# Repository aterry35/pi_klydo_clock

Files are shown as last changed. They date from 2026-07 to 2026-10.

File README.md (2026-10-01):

# Pi Klydo Clock

An offline-first animated art clock for a Raspberry Pi 3 and a portrait 7-inch
DSI display. The repository contains both the native clock renderer and a browser
designer that exports installable clock-face packages.

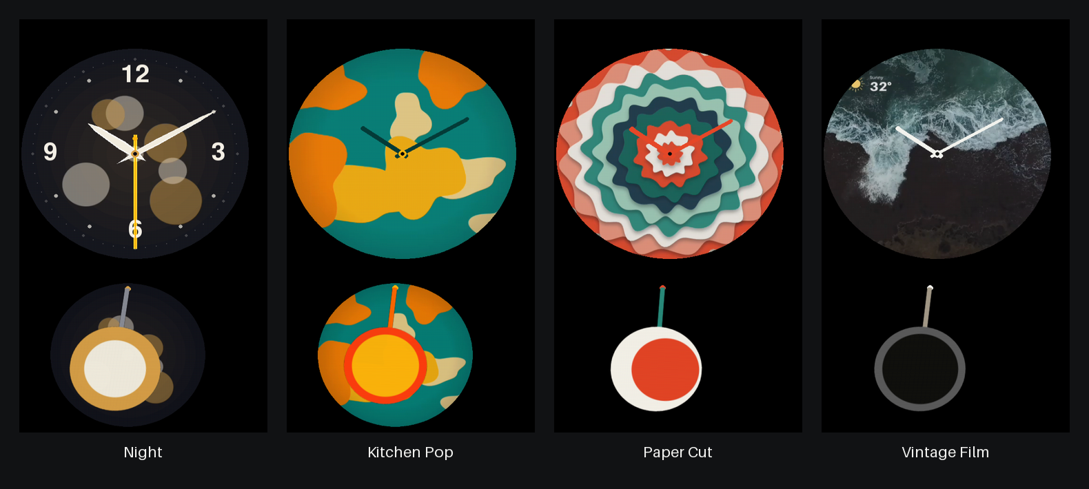
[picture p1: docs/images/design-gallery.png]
Kitchen Pop, Night, Paper Cut, and Vintage Film clock designs


## Highlights

- Native SDL2/Pygame renderer with PyAV video loops; Chromium is not required on the Pi.
- Real-time analog hands rendered independently from the background animation.
- Animated pendulum art with configurable period, amplitude, pivot, and backdrop.
- JSON-configurable display geometry shared by the renderer and design tool.
- Built-in designs plus SD-card and SCP design-folder discovery after every boot.
- DS3231 RTC support, NTP synchronization, and SoftAP Wi-Fi provisioning.
- Four-second dial hold opens an on-device network recovery panel.
- Optional MQTT face selection by folder ID, with retained state and face catalogue.
- React/Vite designer with deterministic H.264 export and package validation.
- Public community gallery with artist profiles, watermarks, likes, comments, reports, and ZIP downloads.
- Private moderation dashboard with hide/restore, artist suspension, and an audit history.

The target enclosure uses a **480 x 800** display behind two circular cutouts:

- **Top circle** — a **400 px** looping design video/animation with **real-time analog hands
  composited on top as an independent layer** (the hands are driven by the clock, not
  the video, so they stay correct no matter what the animation does). The background
  fills the complete opening; the 3D-printed faceplate supplies the visible edge.
- **Bottom circle** — a **300 px themed swinging pendulum**, colour/period/amplitude matched
  to the active design.

Designs live on the SD card, one folder each. Timekeeping supports a **DS3231 RTC** (correct
with no network); Wi-Fi is provisioned via a **SoftAP captive portal** without touching
the display.

See [`DESIGN_REVIEW.md`](DESIGN_REVIEW.md) for why this replaced the original Chromium/HTML
artifact (kept in [`legacy/`](legacy/)). See [`UI_CONFIGURATION.md`](UI_CONFIGURATION.md)
for the design-folder contract, daily/manual selection logic, and future GPIO/remote
control extension points.

---

## Repo layout

```
DESIGN_REVIEW.md        findings on the old HTML + the architecture decision
UI_CONFIGURATION.md     design-folder schema, controls, AI design contract
COMMUNITY_DESIGNS.md    SD-card/SCP copy workflow + artist package contract
config/clock.json       shared device geometry, folders, and design limits
docs/images/            renderer-generated design screenshots for documentation
3d_enclosure/*.stl      printable frame, faceplate, and rear enclosure meshes
deploy/                 public designer Caddy configuration and deployment notes
community/              Flask API, SQLite schema, design storage, seeding, and backups
Tools/clock-design-creator-app/app/
                        Browser editor for building validated design ZIPs
CLAUDE_DESIGN_APP_PROMPT.md prompt for building a design creator app
legacy/Pi Clock.html    the original bundled-React artifact (kept, untouched)
designs/<name>/         one folder per design (fully self-describing)
  loop.mp4|webm         background animation for the top circle (480×480)
  pendulum.png|svg      pendulum sprite (pivot at top-centre)
  theme.json            hands, dial, pendulum physics, ambiance
src/piclock/            the renderer (see cli.py for entry point)
scripts/                install, validation, generators, and preview rendering
provisioning/           comitup.conf (SoftAP captive portal)
systemd/                renderer, network helper, and RTC-sync units
boot/                   config.txt snippet + cmdline.txt notes
```

On the Pi, community/user designs are also scanned at startup from:

```text
/boot/firmware/piclock-designs/
/boot/piclock-designs/
~/piclock-designs/
```

---

## 3D-printable enclosure

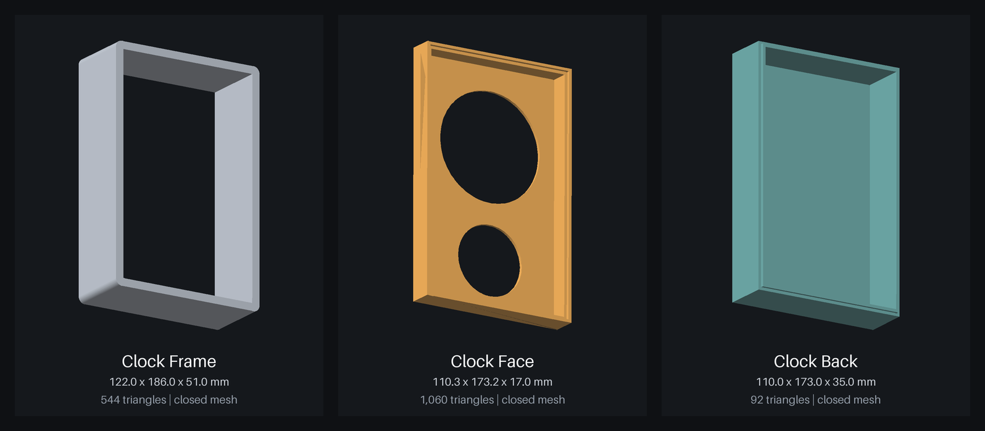
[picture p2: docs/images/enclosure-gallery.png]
Clock frame, faceplate, and rear enclosure STL previews


The [`3d_enclosure/`](3d_enclosure/) directory contains the three closed, manifold
binary STL meshes used for the clock enclosure. Import them into the slicer at 100%
scale and interpret the unitless STL coordinates as millimetres.

| File | Part | Mesh bounding box |
| --- | --- | --- |
| [`clock_frame.stl`](3d_enclosure/clock_frame.stl) | Outer frame and surround | 122.0 x 186.0 x 51.0 mm |
| [`clock_face.stl`](3d_enclosure/clock_face.stl) | Front insert with dial and pendulum openings | 110.34 x 173.216 x 17.0 mm |
| [`clock_back.stl`](3d_enclosure/clock_back.stl) | Rear enclosure shell | 110.0 x 173.0 x 35.0 mm |

The dimensions above are axis-aligned mesh bounds, not recommended print
orientation. Confirm display fit, connector clearance, shrinkage, and printer
tolerances before a production print. Regenerate the documentation renders after
changing an STL with:

```bash
./.venv/bin/python scripts/render_stl_previews.py
```

---

## Quick start (development, on a Mac/PC)

```bash
python3 -m venv .venv && ./.venv/bin/pip install -r requirements.txt
./.venv/bin/python scripts/make_sample_design.py         # writes examples/testcard/
cd src && ../.venv/bin/python -m piclock.cli --windowed --designs ../examples \
  --state ../.piclock-state.json
```

A 480×800 window opens with the sample design. **Controls:** click/tap the top circle (or
`←`/`→`) to cycle designs and persist a manual choice; `d` returns to daily rotation;
`space` toggles night dimming; `esc`/`q` quits.

## Run the design creator

The public community site is available at
<https://designer.18-191-209-51.sslip.io>. It is a community-led, open-source,
non-commercial project: the service does not currently charge artists, sell
submitted designs, or run advertising. Project contact:
<agnel.terry@gmail.com>.

Public routes:

- `/` — project invitation, featured designs, and artist/maker entry points
- `/artists` — browser designer, attribution, licensing, and review guide
- `/designer` — the production clock-face creator
- `/community` — approved designs, likes, comments, reports, and downloads
- `/build` — Raspberry Pi, display, enclosure, installation, and recovery guide
- `/admin` — private review and moderation dashboard

Local editing and ZIP export do not require an account. Submitting to the
Community page requires an artist account.
New packages remain private until an administrator reviews and approves them;
approved packages, previews, likes, and comments are stored by the community API.

```bash
cd Tools/clock-design-creator-app/app
npm install
npm run dev
```

Open the URL printed by Vite in current Chrome or Edge. The editor keeps imported
media local, previews the production enclosure geometry, and exports a ZIP containing
`loop.mp4`, `pendulum.png`, `theme.json`, a preview, and a validation report.

```bash
npm test
npm run build
```

See [`Tools/clock-design-creator-app/README.md`](Tools/clock-design-creator-app/README.md)
for the complete editor and export contract. See
[`COMMUNITY_SOFT_OPENING.md`](COMMUNITY_SOFT_OPENING.md) for the hosted service,
operating procedure, backups, and soft-opening limitations.

---

## Designs & `theme.json`

A design folder **fully defines** the design — there are no hardcoded assets. Anything
missing degrades gracefully (a flat accent disc / procedural pendulum), so a folder with
only a partial `theme.json` still renders.

```jsonc
{
  "name": "Test Card",
  "creator": {
    "artist": "Artist Name",
    "watermark": "Artist Name",
    "watermark_enabled": true,
    "watermark_color": "#ffffff",
    "watermark_opacity": 0.65
  },
  "accent": "#d9a24a",          // hub, pendulum ring, dial accents
  "background": "#050505",       // used when day_night is off
  "hands": {
    "hour":   { "color": "#f0c070", "width": 12, "length": 0.52,
                "glow": true, "shape": "spindle" },
    "minute": { "color": "#f7e1d3", "width": 7,  "length": 0.78,
                "glow": true, "shape": "spindle" },
    "second": { "color": "#e0564a", "width": 3,  "length": 0.90,
                "glow": true, "visible": true }
  },
  "dial":     { "markings": "ticks", "color": "#ffffff", "count": 12 },
  "pendulum": { "period_s": 2.0, "amplitude_deg": 13,
                "pivot": [0.5, 0.05], "rod_length": 0.82 },
  "bottom":   { "backdrop": "loop", "color": "#050505" },
  "ambiance": { "day_night": true, "twinkle": true, "glow": true }
}
```

- `length` / `rod_length` are fractions of the circle radius/diameter.
- Set a hand's `visible` to `false` for clean Klydo-style designs with no
  second hand.
- `shape` can be `spindle` for pointed clock hands or `rounded` for clean
  baton hands like the Klydo reference photos.
- `pivot` is `[x, y]` as a fraction of the bottom circle's bounding box.
- `period_s` = one full left→right→left swing; `amplitude_deg` = peak angle.
- `bottom.backdrop` can be `loop`, `solid`, or `none`; use `solid` plus a
  `color` for reference designs where the pendulum sits on a plain cutout.

### Add a new design
1. Create `designs/my-design/`.
2. Drop in a **480×480** `loop.mp4` (H.264, short seamless loop) and a `pendulum.png`
   or `pendulum.svg` (transparent artwork, pivot at top-centre).
3. Write a `theme.json` (copy `examples/testcard/theme.json` and edit).
4. Cycle to it on the device (tap/swipe the top circle). No code changes, no restart
   config — the folder is discovered at startup.

For community designs, copy the complete folder to
`/boot/firmware/piclock-designs/` by mounting the SD card on a laptop, or SCP it
to `~/piclock-designs/` on the Pi. Power-cycle or restart the renderer to scan
new folders. See `COMMUNITY_DESIGNS.md` for the full package contract.

To create a package in the browser, run the production editor in
`Tools/clock-design-creator-app/app/`. Its README includes installation,
browser support, testing, and export instructions.

By default the renderer starts in **daily** mode: it chooses a deterministic design for
the current date. Tap/swipe/arrow keys switch to a manual design and save that choice in
the state file. Press `d` to return to daily rotation.

Hold the upper dial without moving for four seconds to open **Network Recovery**.
The normal tap action is suppressed after a successful long press. The panel shows
connection state, current IP address, nearby SSIDs, refresh, and close controls.

`scripts/make_sample_design.py` shows how to generate a loop + pendulum + theme
programmatically (it uses PyAV to encode, so no system ffmpeg is required).

## Clock-wide JSON configuration

See [`docs/MQTT_CONTROL.md`](docs/MQTT_CONTROL.md) for MQTT configuration, topics,
and remote face selection. MQTT is disabled by default; device configuration
enables it without changing any design folders.

Device registration was previously split between code and systemd command-line
arguments. It now comes from [`config/clock.json`](config/clock.json), which is
also consumed by the browser designer.

The renderer merges the bundled file with persistent device and SD-card overrides:

```text
/opt/piclock/config/clock.json
/etc/piclock/clock.json
/boot/piclock-config.json
/boot/firmware/piclock-config.json
```

Later files win and may contain only changed fields. To tune the remaining left/right
registration without changing any design package:

```json
{
  "layout": {
    "dial": { "center": [224, 260] },
    "pendulum": { "center": [210, 650] }
  }
}
```

The installer preserves `/etc/piclock/clock.json` on later upgrades. See
[`config/README.md`](config/README.md) for precedence and the complete field guide.
Per-design art remains in `theme.json`; physical positions must not be copied into
every design.

---

## DS3231 RTC wiring (Raspberry Pi 3, I2C1)

| DS3231 pin | Pi header pin | Signal |
|---|---|---|
| VCC | Pin 1 | 3.3 V  |
| GND | Pin 6 | GND |
| SDA | Pin 3 | GPIO2 / SDA1 |
| SCL | Pin 5 | GPIO3 / SCL1 |

The [`config.txt` snippet](boot/config.txt.snippet) enables I2C and loads
`dtoverlay=i2c-rtc,ds3231`. After install + reboot, verify:

```bash
i2cdetect -y 1     # a device at 0x68 (shows "UU" once the kernel driver claims it)
sudo hwclock -r    # reads the DS3231
```

`install.sh` removes `fake-hwclock` so the DS3231 becomes the real time source — the
clock is correct on power-up **with no network**. When Wi-Fi is available and NTP syncs,
`piclock-rtc-sync` writes the corrected time **back** to the DS3231 (hourly + shortly
after boot). With no network it is a no-op, so the RTC is never overwritten with drift.

---

## Portrait rotation (display and touch are SEPARATE)

**Display** — preferred: rotate at the framebuffer via the kernel cmdline (zero per-frame
cost), e.g. `video=DSI-1:800x480@60,rotate=90`. See
[`boot/cmdline.txt.notes`](boot/cmdline.txt.notes) for how to find your DSI connector
name. In-app fallback: `--rotate 90`.

Some 800x480 DSI panels use rectangular physical pixels, which makes a pixel-perfect
circle appear taller than it is wide after portrait rotation. Set
`display.circle_y_scale` to correct each complete dial and pendulum layer without
moving its centre. Measure the displayed width and height and use `width / height` as
the factor. This project's measured panel uses `0.925`.

The default circle centres are registered to the printed 102 x 165 mm front panel:
the 76 mm dial opening starts at `(14.9954, 16.4983)` mm and the 48.5 mm pendulum
opening starts at `(29.0742, 107.4681)` mm. Background layers overscan those
openings; the enclosure supplies the visible black border.

Enclosure registration is global rather than part of a design package. Set
`layout.dial.center` and `layout.pendulum.center` in the device JSON to move all
designs together. The current enclosure calibration uses `(224,260)` for the dial
and `(210,650)` for the pendulum.
The CLI offset options remain available only for temporary on-device experiments.

**Touch** — rotating the display does **not** rotate the touch matrix. Two options:
- In-app: `--touch-rotate 90` (the renderer rotates normalised finger coords).
- System: a libinput calibration matrix via udev, e.g.
  ```
  # /etc/udev/rules.d/99-piclock-touch.rules  (90° example)
  ENV{LIBINPUT_CALIBRATION_MATRIX}="0 -1 1 1 0 0"
  ```
Tune the exact value on-device; touch calibration is inherently panel-specific.

---

## Wi-Fi provisioning (SoftAP captive portal, via comitup)

The clock UI runs regardless of network state. If no known network connects on boot,
[comitup](provisioning/comitup.conf) raises an open access point **`PiClock-XXXX`**:

1. On your phone, join `PiClock-XXXX` → a captive portal opens.
2. Pick your Wi-Fi network and enter the password.
3. The Pi drops the AP, joins your network, and NTP→RTC writeback runs.

The clock keeps rendering through the whole flow. For recovery from a stale or incorrect
saved network, hold the upper dial for four seconds and choose **Start Setup Hotspot**.
The panel requires a second confirmation because this operation removes all saved Wi-Fi
profiles, disconnects any SSH session, and returns Comitup to hotspot mode. Join the shown
`PiClock-XXXX` network on a phone and use its captive portal to enter the replacement Wi-Fi
credentials. After connection, the recovery panel shows the DHCP address directly; Comitup
also advertises its `PiClock-XXXX.local` mDNS name through Avahi.

The renderer remains unprivileged. Network status, scanning, and the confirmed Comitup
reset pass over `/run/piclock-network/control.sock` to the root-owned
`piclock-network.service`, whose protocol allowlists only those three operations.

Useful diagnostics after installation:

```bash
systemctl status NetworkManager comitup comitup-web piclock-network
journalctl -u comitup -u comitup-web -u piclock-network -b
nmcli device status
```

---

## Boot-time tuning (applied)

Targeting fast power-on → first frame on a DSI panel (no HDMI):

- **No HDMI probing** — `dtoverlay=vc4-kms-v3d,nohdmi` disables HDMI outputs (DSI panel).
- **No splash / quiet boot** — `disable_splash=1`, and cmdline `quiet loglevel=1
  logo.nologo plymouth.enable=0 vt.global_cursor_default=0 fastboot`.
- **Renderer starts before Wi-Fi** — `piclock-renderer.service` orders after `local-fs`
  only and never references `network-online.target`, so the first frame is not gated on
  Wi-Fi. `getty@tty1` is disabled so the app owns the console.
- **`boot_delay=0`**, `Restart=always` watchdog on the renderer.

### Read-only root (SD longevity — optional, recommended)
An always-on appliance benefits from a read-only root to avoid SD wear/corruption. Enable
via `raspi-config` → *Performance* → *Overlay File System*, or `raspi-config nonint
enable_overlayfs`. Keep these paths writable:
- the DS3231 needs none (it is hardware), but `hwclock` drift files under `/var` do;
- comitup stores connection profiles under `/etc/NetworkManager/system-connections`.
Put those on a small writable overlay/tmpfs exception, or provision Wi-Fi once before
switching root to read-only. Designs on the SD card are read-only by nature.

---

## Install on the Pi

```bash
git clone https://github.com/aterry35/pi_klydo_clock.git piclock
cd piclock
sudo bash scripts/install.sh
```

The installer defaults the wireless regulatory country to `US`. Override it when needed:

```bash
sudo PICLOCK_WIFI_COUNTRY=CA bash scripts/install.sh
```

The installer (idempotent) installs deps, deploys to `/opt/piclock`, builds the venv
(via piwheels), enables I2C + the DS3231, configures the Wi-Fi country, appends the
`config.txt` block, installs NetworkManager/Comitup/captive-portal support and the
systemd units, and disables `getty@tty1`. On Bookworm it first installs Comitup's
official APT source package to obtain the required NetworkManager Python bindings;
installation now stops if SoftAP support cannot be installed.
It then prints the **manual** cmdline.txt step (not automated — a bad cmdline can prevent
boot) and the DS3231 verification commands.

By default, the renderer service runs as the sudo/login user that ran the installer
(for this Pi, that means the display-owning desktop user). Override with
`PICLOCK_USER=piclock sudo bash scripts/install.sh` if you want a dedicated service user,
then validate DRM/input permissions on the physical Pi.

```bash
systemctl status piclock-renderer
journalctl -u piclock-renderer -b
```

> **DRM master note:** running an SDL kmsdrm app straight from systemd (no compositor)
> requires the process to become DRM master on tty1. The provided unit takes the VT and
> runs in the `video`/`render`/`input` groups; if the display stays black, check
> `journalctl -u piclock-renderer -b` for a DRM permission error and confirm `getty@tty1`
> is disabled. This is the one piece that can only be validated on the physical Pi.

---

## What is verified vs. Pi-only

Verified on a development machine: design-folder discovery + `theme.json`, PyAV loop decode,
the two-layer composite, **hands decoupled from the video**, pendulum swing, circle-only
day/night ambiance + twinkle, graceful fallback for asset-less designs, design cycling,
and persisted daily/manual selection.

Verified on the project Pi: KMS portrait rendering, JSON geometry overrides, systemd
startup, design discovery, persistent selection, and native H.264 playback. DS3231 wiring
and the complete captive-portal/long-press recovery flow still require validation after
the freshly imaged Pi is available.

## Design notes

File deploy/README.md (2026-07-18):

# Designer deployment

The production designer is served by Caddy at:

<https://designer.18-191-209-51.sslip.io>

The root serves the public landing page. Clean SPA paths include `/artists`,
`/designer`, `/community`, `/build`, and `/admin`; Caddy's `try_files` fallback
routes direct requests for each page to the Vite application.

The hostname uses `sslip.io` DNS to resolve to the EC2 public IP. Caddy obtains and
renews the TLS certificate automatically. Ports 80 and 443 must be allowed by the
instance's EC2 security group.

## Deploy an update

From the repository root:

```bash
DESIGNER_KEY=Amazon_certificate/Terryt.pem ./scripts/deploy_designer_ec2.sh
```

The script runs the designer and API tests, builds the Vite application, uploads
timestamped frontend and backend releases, seeds the bundled designs into the
community gallery, validates Caddy, and atomically changes each `current` symlink.
Previous frontend releases remain under `/var/www/pi-clock-designer/releases/` and
backend releases under `/opt/pi-clock-community/releases/` for rollback.

## Services and data

```text
piclock-community.service          Gunicorn/Flask API on 127.0.0.1:8080
piclock-community-backup.timer     daily SQLite backup with 14-day retention
/var/lib/pi-clock-community/       database, uploaded ZIPs/previews, and backups
/opt/pi-clock-community/current/   active API release
/var/www/pi-clock-designer/current active frontend release
/etc/piclock-community.env       private agent token hash and agent identity
```

Caddy serves the frontend and proxies `/api/*` to Gunicorn. Check the deployed
service with:

```bash
curl https://designer.18-191-209-51.sslip.io/api/health
ssh -i Amazon_certificate/Terryt.pem ubuntu@18.191.209.51 \
  'sudo systemctl status piclock-community --no-pager'
```

The EC2 instance is the only application host during the soft opening. Backups are
local to that instance, so copy them off-host before treating the service as durable.
See `COMMUNITY_SOFT_OPENING.md` for current limits and operating steps.

Promote an existing account without handling its password:

```bash
cd /opt/pi-clock-community/current
sudo -u piclock-community env PICLOCK_DATA_DIR=/var/lib/pi-clock-community \
  /opt/pi-clock-community/venv/bin/python -m community.manage promote \
  --email administrator@example.com
```

The private key is excluded by `*.pem` in the repository `.gitignore` and must never be
copied into the web root or committed to Git.

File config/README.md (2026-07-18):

# Clock Configuration

`clock.json` is the shared source of truth for device-wide rendering and design
package limits. Both the native clock renderer and the browser designer read it.

The calibrated Pi layout and the browser preview use separate center settings.
This keeps artwork centered in the designer without changing its alignment with
the physical enclosure on the clock.

## Configuration Levels

The clock deliberately uses two JSON levels:

- `clock.json` controls the physical device: display, circle positions, size
  limits, enclosure measurements, design folders, and asset requirements.
- Each design folder's `theme.json` controls its artwork: hands, dial markings,
  circle diameter within the allowed range, pendulum motion, and colors.

Physical registration does not belong in every design. Changing a center in
`clock.json` moves every installed design together.

## Load Order

The renderer merges these files in order. Later values override earlier values:

1. `/opt/piclock/config/clock.json` (installed project defaults)
2. `/etc/piclock/clock.json` (persistent device calibration)
3. `/boot/piclock-config.json` (older Raspberry Pi OS boot partition)
4. `/boot/firmware/piclock-config.json` (Bookworm boot partition)
5. Any file passed with `--config`

The installer initializes `/etc/piclock/clock.json` from
`device-clock.example.json` only when the device file does not already exist.
Subsequent installs preserve the device calibration.

Override files may contain only the fields that need changing. For example:

```json
{
  "layout": {
    "dial": { "center": [224, 260] },
    "pendulum": { "center": [210, 650] }
  }
}
```

After changing a file on the Pi, restart the renderer:

```bash
sudo systemctl restart piclock-renderer
```

Invalid override files are reported in the service journal and ignored so that
a malformed SD-card configuration cannot stop the clock from booting.

## Main Fields

| JSON path | Purpose |
|---|---|
| `display.mode` | `kms` on the Pi or `windowed` for desktop use. |
| `display.width`, `display.height` | Portrait render canvas. |
| `display.rotate`, `display.touch_rotate` | Display and touch orientation. |
| `display.circle_y_scale` | Physical pixel aspect correction. |
| `layout.dial.center` | Upper circle center `[x, y]` in canvas pixels. |
| `layout.pendulum.center` | Lower circle center `[x, y]` in canvas pixels. |
| `designer.preview.dial_center` | Upper circle center used only by the browser designer and exported preview image. |
| `designer.preview.pendulum_center` | Lower circle center used only by the browser designer and exported preview image. |
| `network.enabled` | Enables the on-device long-press network recovery panel. |
| `network.interface` | NetworkManager Wi-Fi device controlled by the helper. |
| `network.control_socket` | Renderer/helper Unix socket under `/run/piclock-network`. |
| `network.long_press_seconds` | Stationary upper-dial hold duration required to open recovery. |
| `network.max_visible_networks` | Number of nearby SSIDs shown inside the dial. |
| `layout.*.minimum_diameter` | Smallest diameter accepted from `theme.json`. |
| `layout.*.default_diameter` | Default and designer starting diameter. |
| `layout.*.maximum_diameter` | Largest accepted/designer diameter. |
| `designs.system_directory` | Built-in design folder. |
| `designs.user_directories` | Ordered SD-card/SCP scan folders. |
| `designs.state_path` | Persisted manual/daily selection. |
| `designs.assets` | Export canvas, frame-rate, and duration requirements. |
| `enclosure` | CAD reference measurements in millimeters. |

Command-line geometry options remain available for temporary diagnosis, but
production calibration should be saved in a JSON override.

The default browser preview centers both circles at `x = 240` on the 480 px
canvas. The Pi keeps its enclosure-calibrated centers under `layout`; changing
the `designer.preview` values does not move installed clock designs.

Network recovery values are device-wide. If `control_socket` is overridden, the
root helper only accepts paths directly under `/run/piclock-network`; this prevents
an SD-card override from replacing arbitrary system files.

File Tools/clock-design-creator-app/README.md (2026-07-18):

# Pi Clock Design Creator

The production React/Vite source is in `app/`.

## Run The Editor

```bash
cd Tools/clock-design-creator-app/app
npm install
npm run dev
```

Open the local URL printed by Vite. Editing and local ZIP export do not require an
account, and imported media stays in the browser until the user publishes. Publishing
uploads the validated package and preview to the Community gallery.

The editor requires a current Chromium browser with WebCodecs H.264 support.
Chrome and Edge are the supported export browsers.

The built-in starting points include dedicated Kitchen Pop and Paper Cut
generators. Both are fully procedural, so their animation, palette, hands,
pendulum proportions, and circle sizes remain editable before export.

The preview uses the production enclosure registration: a 76 mm dial opening and
48.5 mm pendulum opening on the 102 x 165 mm printed face. Background-size controls
retain overscan so the recessed display does not expose a black edge through either
opening.

The editor imports the repository's `config/clock.json` directly. Preview centers,
circle diameter limits, CAD measurements, output canvas sizes, frame-rate limits,
and duration limits therefore stay synchronized with the native renderer. Restart
Vite after changing that file if hot reload does not pick up an external JSON edit.

## Community publishing

The Community page is publicly readable. Registering an artist account enables
design submission, likes, and comments. The artist name is written into `theme.json`,
shown on gallery cards, and must match the signed-in profile when submitting. Community
submissions require an enabled dial watermark; the Pi renderer draws it over the
upper dial without baking it into the loop video.

New packages enter a private review queue. The administrator receives an email,
reviews the preview and downloadable package, and then approves or rejects the
submission with a recorded reason. Only approved packages appear in the gallery.
Signed-in users can report a published design, and administrators can also
hide/restore designs, suspend accounts, resolve reports, and inspect the audit log.
Email verification and password reset are not part of the soft opening.

## Build And Test

```bash
npm test
npm run build
```

The production build is written to `app/dist/` and contains local JavaScript and
CSS assets. It does not depend on Google Fonts or a React CDN.

## Export Contract

Every ZIP contains one top-level design folder:

```text
<design-slug>/
  loop.mp4
  pendulum.png
  theme.json
  preview.png
  export-report.json
  README.txt
```

`loop.mp4` is encoded deterministically as 480x480 H.264. The exporter renders
exactly `duration * fps` frames and refuses to package the result if the encoded
frame count does not match.

Validate an extracted design with the project validator:

```bash
python scripts/validate_design.py /path/to/<design-slug>
```

The validator decodes the video and checks resolution, codec, frame rate,
duration, and minimum decoded frame count.

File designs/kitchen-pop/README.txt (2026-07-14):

Kitchen Pop - Pi Clock design package
Made with Pi Clock Design Creator

Contents
  loop.mp4      480x480 H.264 animation, 6s at 15 fps (90 frames)
  pendulum.png  300x400 transparent sprite, pivot at top center
  theme.json    hands, dial, pendulum motion and ambiance
  preview.png   full 480x800 layout snapshot

Install from the SD card
  Copy this folder to piclock-designs/kitchen-pop/ on the boot partition.

Install over the network
  scp -r kitchen-pop terry@192.168.1.217:/home/terry/piclock-designs/

Restart piclock-renderer or power-cycle the clock. Design folders are scanned at startup.

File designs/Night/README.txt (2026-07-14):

Night - Pi Clock design package
Made with Pi Clock Design Creator

Contents
  loop.mp4      480x480 H.264 animation, 8s at 15 fps (120 frames)
  pendulum.png  300x400 transparent sprite, pivot at top center
  theme.json    hands, dial, pendulum motion and ambiance
  preview.png   full 480x800 layout snapshot

Install from the SD card
  Copy this folder to piclock-designs/night/ on the boot partition.

Install over the network
  scp -r night terry@192.168.1.217:/home/terry/piclock-designs/

Restart piclock-renderer or power-cycle the clock. Design folders are scanned at startup.

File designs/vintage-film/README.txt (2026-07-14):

Vintage Film - Pi Clock design package
Made with Pi Clock Design Creator

Contents
  loop.mp4      480x480 H.264 animation, 7.03s at 15 fps (105 frames)
  pendulum.png  300x400 transparent sprite, pivot at top center
  theme.json    hands, dial, pendulum motion and ambiance
  preview.png   full 480x800 layout snapshot

Install from the SD card
  Copy this folder to piclock-designs/vintage-film/ on the boot partition.

Install over the network
  scp -r vintage-film terry@192.168.1.217:/home/terry/piclock-designs/

Restart piclock-renderer or power-cycle the clock. Design folders are scanned at startup.

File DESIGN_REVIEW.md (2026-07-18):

# Design Review - Pi Klydo Clock

## 1. Reference Target

The Klydoclock reference is not just an analog clock skin. It is closer to a
small media appliance: a circular animated artwork, analog hands rendered over
that artwork, and a changing content library/daily feed. The useful product
idea to copy is the separation of responsibilities:

- the animation is authored media;
- the clock hands are a live, correct time layer;
- designs are content packages, not code changes.

The physical target here is different from the commercial product: a Raspberry
Pi 3 with a 7" DSI panel in portrait, 480x800, behind a 3D-printed faceplate
with two circular cutouts. That means the fixture geometry matters as much as
the graphics.

## 2. Current Legacy HTML

The preserved legacy file at `legacy/Pi Clock.html` is a bundled React/x-dc
artifact, not maintainable hand-authored HTML/CSS:

- hands are DOM elements rotated with CSS transforms from `new Date()`;
- designs are hardcoded theme objects inside minified JavaScript;
- backgrounds are CSS gradients/keyframes, not external artwork packages;
- the pendulum exists, but period/amplitude are fixed in CSS;
- input is keyboard/WebSocket oriented, not touch-first;
- there is no RTC, provisioning, systemd, design-folder loading, or boot path.

The legacy version is visually useful and should remain as reference material,
but it is the wrong runtime for the appliance.

## 3. What To Keep

- Two-circle composition: large clock dial above, smaller pendulum below.
- Live analog hands over the design layer.
- Themed pendulum matched to the active design.
- Day/night/twinkle idea from the old implementation, but as a subtle live
  overlay inside the circular cutouts rather than a browser background.
- Keyboard cycle controls as a fallback.
- The black border/ring around the circles; it is useful for bezel alignment
  and hides small fixture tolerances.

## 4. What To Replace

- Chromium kiosk as the primary renderer.
- Hardcoded theme arrays and bundled JS assets.
- CSS-only "designs" as the final content model.
- Any boot path that waits for Wi-Fi before showing the clock.
- Any installer/service path that assumes the display user can be changed
  freely without validating DRM/KMS ownership on the actual Pi.

## 5. Renderer Decision

**Chosen path: native SDL2 via pygame-ce, with PyAV for small video loops.**

For this hardware revision the video loops are at most 480x480, not 1080p. That
removes the strongest reason to keep Chromium or a dedicated video player.

| Option | Verdict |
|---|---|
| Chromium kiosk | Visually close and easy for CSS, but slow cold start, high RAM use, browser/compositor complexity, and more moving parts at boot. |
| mpv/GStreamer with overlay | Strong video path, but hand/dial overlay synchronization becomes the hard part. It optimizes video decode while making the clock layer fragile. |
| Native SDL2 + PyAV | One process owns the frame loop, hands are structurally independent of the video, touch can be handled directly, and the app can be tested on the Mac before Pi deployment. |

This is still performance-sensitive on a Pi 3. The loops must stay small and
short, and the renderer should avoid per-frame scaling/allocations where
possible. The current app caches the lower-circle scaled frame while the source
video frame is unchanged.

## 6. Approved Architecture

The app now follows this model:

```text
designs/<name>/
  loop.mp4 | loop.webm | loop.mkv
  pendulum.png | pendulum.svg
  theme.json
```

At runtime:

1. Scan the design folders at startup.
2. Pick the daily design by default.
3. Let touch/swipe/keyboard select a manual design and persist it.
4. Allow keyboard `d` to return to daily rotation.
5. Decode the top-loop frame into the 400 px top circle.
6. Apply a subtle live ambiance/twinkle overlay inside the circular cutouts.
7. Draw dial markings and real-time hands over the top circle.
8. Draw the themed pendulum over a 300 px lower design backdrop.

The fixed geometry is currently:

- screen: 480x800;
- top cutout: 400 px diameter, calibrated at x=224, y=260;
- bottom cutout: 300 px diameter, calibrated at x=210, y=650;
- fixture ring: 18 px black stroke.

Those values match the current fixture direction and should become the first
things to tune when the printed bezel dimensions are final.

## 7. Raspberry Pi Integration

The renderer should run before networking:

- systemd renderer service starts after local filesystems, not
  `network-online.target`;
- RTC provides correct time without Wi-Fi;
- Wi-Fi provisioning is handled by Comitup SoftAP/captive portal and does not
  block the renderer. A four-second dial hold opens recovery; its root helper
  exposes only status, scan, and confirmed hotspot-reset actions;
- NTP, when available, writes corrected time back to the DS3231.

The installer defaults the renderer service user to the sudo/login user because
that matches the display ownership path proven on the current Pi. It can still
be overridden with `PICLOCK_USER=piclock` for a dedicated service account, but
that path must be validated on-device for DRM master/input permissions.

## 8. Remaining Validation Risk

These items are written or configured but require the physical Pi:

- DRM/KMS startup on tty1 after a cold boot;
- DSI panel rotation and separate touch rotation;
- Comitup captive portal and long-press recovery while the renderer is active;
- DS3231 overlay/hwclock behavior after power loss;
- real CPU/RAM usage after several hours of looping.

## 9. Recommendation

Stay with the native renderer. It is the better long-term structure for this
appliance and it keeps the Klydo-style split between authored media and live
time. The legacy HTML remains useful as a visual reference, but the production
path should be design folders plus a small native boot service.

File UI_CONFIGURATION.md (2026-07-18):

# UI Configuration Guide

This project is designed so the clock UI can grow by adding **design folders**,
not by editing renderer code for every new clock face.

## What Is Configurable Today

The renderer currently supports:

- multiple designs stored in one directory;
- daily automatic design selection;
- manual design override by touch/swipe or keyboard;
- persisted selected design state;
- four-second upper-dial hold for on-device network recovery;
- per-design video loop artwork;
- per-design pendulum artwork;
- per-design hands, dial markings, pendulum motion, and ambiance settings.

Device-wide geometry and package limits are configured in `config/clock.json`.
Per-design artwork remains in each design folder's `theme.json`. This separation
means one enclosure correction applies to every built-in and user design.

The default production location on the Pi is:

```text
/opt/piclock/designs/
```

User/community designs are also scanned on startup from:

```text
/boot/firmware/piclock-designs/    SD-card copy location
/boot/piclock-designs/             older Raspberry Pi OS fallback
~/piclock-designs/                 SCP/network-copy location
```

The local development location is:

```text
designs/
```

Each design is one folder:

```text
designs/<design-name>/
  loop.mp4 | loop.webm | loop.mkv
  pendulum.png | pendulum.svg
  theme.json
```

The app scans these directories at startup. If you add a new design while the
app is already running, restart `piclock-renderer` so it rescans the folder
list.

## Screen Geometry

The target display is the 7" DSI panel in portrait:

```text
screen: 480 x 800
top circle: 400 px diameter
bottom circle: 300 px diameter
software fixture border: 0 px (the printed face supplies the border)
```

The default layout is registered to the measured 102 x 165 mm enclosure:

```text
dial aperture:      76 mm diameter, starts at x=14.9954 mm, y=16.4983 mm
pendulum aperture:  48.5 mm diameter, starts at x=29.0742 mm, y=107.4681 mm
```

These are enclosure coordinates. Do not convert them directly using 102 mm =
480 px or 165 mm = 800 px because the LCD active area is inset within the
physical panel. The currently calibrated renderer centers are `(224,260)` and
`(210,650)`. Edit `layout.dial.center` and `layout.pendulum.center` in
`/etc/piclock/clock.json` or an SD-card override for future registration changes.
Exported design folders intentionally do not contain device layout offsets. See
`config/README.md` for every clock-wide field and override precedence.

Recommended artwork sizes:

```text
loop video:      480 x 480 maximum, 400 x 400 also acceptable
pendulum image: 300 x 400, transparent background, pivot at top center
```

Keep important artwork inside the physical cutout, but let the background fill
the complete exported frame. The renderer overscans the openings so mounting
tolerance and the 2 mm enclosure depth cannot reveal a software-painted black ring.

## theme.json Schema

Minimal example:

```json
{
  "name": "Kitchen Pop",
  "accent": "#ffb70f",
  "background": "#050505",
  "hands": {
    "hour": {
      "color": "#063d3a",
      "width": 11,
      "length": 0.42,
      "glow": false,
      "shape": "rounded"
    },
    "minute": {
      "color": "#063d3a",
      "width": 9,
      "length": 0.66,
      "glow": false,
      "shape": "rounded"
    },
    "second": {
      "color": "#ffb70f",
      "width": 2,
      "length": 0.85,
      "glow": false,
      "visible": false
    }
  },
  "dial": {
    "markings": "none",
    "color": "#ffffff",
    "count": 12
  },
  "pendulum": {
    "period_s": 1.6,
    "amplitude_deg": 9,
    "pivot": [0.5, 0.035],
    "rod_length": 0.74
  },
  "bottom": {
    "backdrop": "loop",
    "color": "#050505"
  },
  "ambiance": {
    "day_night": false,
    "twinkle": false,
    "glow": false
  }
}
```

### Top-Level Fields

| Field | Purpose |
|---|---|
| `name` | Human-readable design name and persisted selection key. |
| `accent` | Hub, pendulum, and fallback color. |
| `background` | Used for the hand hub center and non-day-night fallback. |
| `hands` | Hour/minute/second hand styling. |
| `dial` | Tick/numeral visibility and color. |
| `pendulum` | Swing motion and pivot. |
| `bottom` | Lower cutout backdrop behind the pendulum. |
| `ambiance` | Optional real-time tint/twinkle overlay. |

### Hands

| Field | Meaning |
|---|---|
| `color` | Hex color. |
| `width` | Stroke/body width in pixels. |
| `length` | Fraction of the top-circle radius. |
| `glow` | Adds soft glow when true. |
| `visible` | Optional; set `false` to hide a hand. Useful for no second hand. |
| `shape` | `spindle` for pointed clock hands, `rounded` for Klydo-style baton hands. |

### Dial

| `markings` | Result |
|---|---|
| `none` | No marks. Best for artwork-led Klydo-style designs. |
| `ticks` | Hour tick marks. |
| `numerals` | 12/3/6/9 numerals with small dots. |
| `both` | Tick marks plus numerals/dots. |

### Pendulum

| Field | Meaning |
|---|---|
| `period_s` | Full left-right-left swing period in seconds. |
| `amplitude_deg` | Peak swing angle. |
| `pivot` | `[x, y]` fraction of the bottom circle bounding box. |
| `rod_length` | Fraction of bottom circle diameter used by procedural fallback. |

For custom pendulum art, use `pendulum.png` or `pendulum.svg` with a transparent
background. The pivot should be at the **top center** of the image.

### Bottom Backdrop

| `backdrop` | Result |
|---|---|
| `loop` | Reuses the top design loop behind the pendulum. This is the default. |
| `solid` | Draws a solid circular backdrop using `color`. |
| `none` | Leaves the lower cutout black before drawing the pendulum. |

## Design Selection Logic

The renderer has two selection modes.

### Daily Mode

Daily mode chooses a deterministic design from the design list based on the
current date. This gives a Klydo-like "new design each day" behavior without a
network connection.

The device JSON starts with:

```text
"startup_mode": "daily"
```

The code path is `DesignSet.daily()` / `DesignSet._select_daily()`.

### Manual Mode

Manual mode is entered when the user cycles designs:

- tap top circle: next design;
- swipe left/right on top circle: next/previous design;
- keyboard right/left: next/previous design;
- keyboard `d`: return to daily mode.

The chosen mode/design is persisted in the state file. On the Pi this is:

```text
/var/lib/piclock/state.json
```

Example:

```json
{
  "mode": "manual",
  "selected": "Kitchen Pop",
  "folder": "kitchen-pop"
}
```

To force daily mode again:

```json
{
  "mode": "daily",
  "selected": "Kitchen Pop",
  "folder": "kitchen-pop"
}
```

Then restart:

```bash
sudo systemctl restart piclock-renderer
```

## Physical Knob / GPIO Control

GPIO knob control is not implemented yet, but the app is already structured for
it. The renderer uses semantic actions:

```text
next_design
prev_design
daily_design
toggle_dim
open_network_settings
close_network_settings
refresh_network_settings
quit
```

Current sources:

- touch;
- mouse for development;
- keyboard.

Recommended implementation for a rotary encoder:

1. Add a small GPIO input module or sidecar service.
2. Map clockwise to `next_design`.
3. Map counter-clockwise to `prev_design`.
4. Map button press to `daily_design` or `toggle_dim`.
5. Keep the renderer action API semantic so GPIO details do not leak into UI code.

For the Pi, a separate service can also write the state file and restart or
signal the renderer. A cleaner future version would add a local UNIX socket or
small HTTP endpoint so remote/GPIO controllers can send actions live.

## Remote Control Options

Remote control is also not implemented yet in the native renderer. The legacy
HTML had a WebSocket bridge, but that was removed with Chromium.

Reasonable future choices:

| Option | Use When |
|---|---|
| Local HTTP API | Phone/app/controller on same Wi-Fi should change design. |
| WebSocket | Need live remote commands without polling. |
| MQTT | Home automation integration. |
| File drop + restart | Simplest maintenance path; safe but not live. |
| GPIO sidecar | Physical knob/button only. |

Suggested API shape:

```text
POST /api/design/next
POST /api/design/prev
POST /api/design/daily
POST /api/design/select {"name": "Kitchen Pop"}
POST /api/dim {"enabled": true}
GET  /api/designs
```

## Adding A New Design Manually

1. Create a new folder:

   ```bash
   mkdir -p designs/my-design
   ```

2. Add a square loop:

   ```text
   designs/my-design/loop.mp4
   ```

3. Add pendulum art:

   ```text
   designs/my-design/pendulum.png
   ```

4. Add `theme.json`.

5. Test locally:

   ```bash
   cd src
   ../.venv/bin/python -m piclock.cli --windowed --designs ../designs \
     --state ../.piclock-state.json
   ```

6. Deploy to Pi:

   ```bash
   sudo rsync -a designs/my-design /opt/piclock/designs/
   sudo systemctl restart piclock-renderer
   ```

## AI Agent Design Contract

If an AI agent creates designs for this project, ask it to produce a complete
folder with this exact structure:

```text
designs/<slug>/
  loop.mp4
  pendulum.png
  theme.json
```

Constraints for generated designs:

- `loop.mp4`: square, 480x480 max, H.264, 12-15 fps, 4-8 seconds, seamless or
  near-seamless loop;
- keep important artwork inside the visible enclosure aperture;
- no clock hands or numerals baked into the video unless intentionally part of
  the artwork;
- `pendulum.png`: transparent, 300x400 recommended, pivot at top center;
- `theme.json`: must set hand colors, hand shape, dial markings, pendulum
  period/amplitude, and ambiance options;
- use `dial.markings: "none"` for artwork-led Klydo-style designs;
- use `hands.second.visible: false` when the design should feel clean and
  product-like.

Example prompt for an AI design agent:

```text
Create a Pi Klydo Clock design folder named "sunny-kitchen".
Target display is 480x800 with a 400px top circle and 300px bottom circle.
Produce:
- loop.mp4, 480x480, 15fps, 6 seconds, seamless, abstract flat artwork;
- pendulum.png, 300x400 transparent PNG, pivot at top center;
- theme.json using rounded dark hands, no dial markings, no second hand.
Keep important artwork inside the visible enclosure aperture.
Return files in designs/sunny-kitchen/.
```

## Current Limitations

- Designs are scanned at startup, not hot-loaded.
- Daily rotation is date-based and deterministic, not tied to downloaded content.
- Touch and keyboard selection work now; GPIO knob and remote API are planned
  extensions.
- Network recovery is available on-screen; display geometry and design configuration
  remain file-based.
- Physical enclosure quality still matters: the black faceplate and wood frame
  are part of the final visual polish, not only software.

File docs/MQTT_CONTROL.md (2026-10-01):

# MQTT face selection

MQTT is optional and disabled by default. Install the updated requirements and
merge the `mqtt` section from `config/mqtt.example.json` into the device's
`/etc/piclock/clock.json`. Preserve its existing layout calibration.
Restart `piclock-renderer` after changing settings.

Use a unique `topic_prefix` and `client_id` for each clock. Credentials are
device-local: `username` comes from configuration, while the password is read
from the environment variable named by `password_env`. Set `tls` to true for
a broker with a trusted TLS certificate and configure its TLS port.

## Topics

| Topic suffix | Behavior |
| --- | --- |
| `/face/set` | Send a folder ID as plain text or `{"face_id":"paper-cut"}` |
| `/face/state` | Retained JSON: selected `face_id`, display `name`, and `mode` |
| `/faces` | Retained array of available `{face_id,name}` entries |
| `/face/result` | Non-retained acknowledgement or validation error |
| `/availability` | Retained `online`/`offline`, including an offline last will |

IDs are the folder names, case-insensitive, not display names or numeric indexes.
Invalid IDs leave selection unchanged. Successful selection enters manual mode
and is saved using the existing state file. Local taps and daily-mode changes
also update the MQTT state topic. A tap or the existing daily command can still
change the face after a remote command.

Publish commands without retain. Retained commands are deliberately ignored so
an old broker message cannot override the locally saved selection on reconnect.
New folders are discovered after a renderer restart as before. MQTT reconnects
automatically; unavailable network/broker does not prevent the clock rendering.

```bash
mosquitto_sub -h BROKER -p PORT -t 'piclock/my-clock/#' -v
mosquitto_pub -h BROKER -p PORT -q 1 \
  -t 'piclock/my-clock/face/set' -m 'paper-cut'
```

The existing EC2 broker was inspected on September 30, 2026: Mosquitto uses an
anonymous TCP listener on port 1884. This does not authenticate publishers or
encrypt traffic. Its address is configured on the deployed device rather than
embedded in the public source.

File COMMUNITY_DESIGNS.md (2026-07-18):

# Community Design Guide

This clock can load community-created dial and pendulum designs from folders on
the Raspberry Pi. A power cycle or renderer restart is enough for the app to
rescan the folders and include new designs.

Design folders do not carry device positions. Circle centers, enclosure geometry,
allowed diameters, and output asset limits live in `config/clock.json`, so one
calibration applies to every community design.

The hosted designer also has a Community page. Anyone can browse and download
published designs. An artist account is required to publish, like, or comment.
The exported ZIP format is the same whether it is downloaded locally or from the
gallery.

Signed-in users can report copyright concerns, inappropriate content, spam, broken
packages, or other issues from the design detail view. Reports enter the private
administrator queue. Hidden designs disappear from all public lists, previews, and
downloads but remain available to administrators for review and restoration.

## Where To Put Designs

The renderer scans these locations at startup:

```text
/opt/piclock/designs/              built-in/system designs
/boot/firmware/piclock-designs/    SD-card copy location
/boot/piclock-designs/             fallback for older Raspberry Pi OS images
~/piclock-designs/                 SCP/network-copy location
```

For this Pi, the SCP path is:

```text
/home/terry/piclock-designs/
```

Use one of these workflows.

## SD Card Copy Workflow

1. Shut down the Pi.
2. Remove the SD card and mount it on a computer.
3. Open the visible boot partition.
4. Create this folder if it does not exist:

   ```text
   piclock-designs/
   ```

5. Copy complete design folders into it.
6. Put the SD card back in the Pi and power on.

Example final SD-card layout:

```text
piclock-designs/
  sunny-kitchen/
    loop.mp4
    pendulum.png
    theme.json
  blue-orbit/
    loop.mp4
    pendulum.png
    theme.json
```

## SCP Workflow

Copy a finished design folder over the network:

```bash
scp -r sunny-kitchen terry@192.168.1.217:/home/terry/piclock-designs/
```

Then restart the renderer or power-cycle the Pi:

```bash
ssh terry@192.168.1.217
sudo systemctl restart piclock-renderer
```

## Required Folder Format

Each design must be one folder:

```text
<design-slug>/
  loop.mp4
  pendulum.png
  theme.json
```

Use a unique folder slug such as `sunny-kitchen`, `blue-orbit`, or
`paper-bloom`. Folder slugs are compared without regard to letter case. If a
user design has the same slug as a built-in design, the user design overrides
the built-in version. The SCP location is scanned last and therefore has the
highest priority when the same slug exists in multiple user locations.

New folders become available after the next renderer start. An existing manual
selection is preserved, so copying a folder does not automatically replace the
currently displayed design; tap or swipe the top circle to cycle to it.

## Dial Animation

File:

```text
loop.mp4
```

Requirements:

- 480 x 480 pixels.
- H.264 MP4 is preferred.
- 15 fps is preferred for Raspberry Pi 3.
- 4 to 10 seconds is preferred.
- Seamless or near-seamless loop.
- No audio track needed.
- Keep file size modest; under 20 MB is a good target.

The clock draws the real-time hands over this animation, so the animation
should not include clock hands unless that is intentional.

## Pendulum Art

File:

```text
pendulum.png
```

Requirements:

- Transparent PNG.
- 300 x 400 pixels recommended.
- Pivot point at the top center of the image.
- The app rotates this artwork live, so the pendulum image should be drawn
  straight down in its neutral center position.

SVG pendulums are also supported as `pendulum.svg`, but PNG is the safest
format for community submissions.

## Theme File

File:

```text
theme.json
```

Example:

```json
{
  "name": "Sunny Kitchen",
  "creator": {
    "artist": "A. Artist",
    "watermark": "A. Artist",
    "watermark_enabled": true,
    "watermark_color": "#ffffff",
    "watermark_opacity": 0.65
  },
  "accent": "#ffb70f",
  "background": "#050505",
  "hands": {
    "hour": {
      "color": "#063d3a",
      "width": 11,
      "length": 0.42,
      "glow": false,
      "shape": "rounded"
    },
    "minute": {
      "color": "#063d3a",
      "width": 9,
      "length": 0.66,
      "glow": false,
      "shape": "rounded"
    },
    "second": {
      "color": "#ffb70f",
      "width": 2,
      "length": 0.85,
      "glow": false,
      "visible": false
    }
  },
  "dial": {
    "markings": "none",
    "color": "#ffffff",
    "count": 12,
    "diameter": 400
  },
  "pendulum": {
    "period_s": 1.6,
    "amplitude_deg": 9,
    "pivot": [0.5, 0.035],
    "rod_length": 0.74
  },
  "bottom": {
    "backdrop": "solid",
    "color": "#000000",
    "diameter": 300
  },
  "ambiance": {
    "day_night": false,
    "twinkle": false,
    "glow": false
  }
}
```

Useful values:

- `hands.hour` and `hands.minute` control the real clock hands.
- `creator.artist` identifies the artist in the gallery and package metadata.
- `creator.watermark` is rendered on the upper dial by the Pi clock. Community
  publishing requires the watermark to be enabled.
- Set `hands.second.visible` to `false` for a clean art-clock face.
- `shape` can be `rounded` or `spindle`.
- `dial.markings` can be `none`, `ticks`, `numerals`, or `both`.
- `dial.diameter` controls the upper background circle from 400 to 500 pixels.
- `bottom.backdrop` can be `loop`, `solid`, or `none`.
- `bottom.diameter` controls the pendulum background circle from 260 to 340 pixels.
- `pendulum.period_s` controls swing speed.
- `pendulum.amplitude_deg` controls swing width.

## Validate Before Copying

From the project folder:

```bash
python scripts/validate_design.py designs/sunny-kitchen
```

On the Pi:

```bash
cd /opt/piclock
.venv/bin/python scripts/validate_design.py /home/terry/piclock-designs/sunny-kitchen
```

The validator checks for the required files, JSON format, video size, and
pendulum image basics. It reads the same clock configuration as the renderer;
use `--config /path/to/override.json` to validate against an additional override.

## Expected Final Output From A Designer

A designer should deliver one complete folder:

```text
sunny-kitchen/
  loop.mp4
  pendulum.png
  theme.json
```

Optional files such as `preview.png`, `source.psd`, or `notes.txt` are fine, but
the clock only needs `loop.mp4`, `pendulum.png`, and `theme.json`.

## Browser Design Creator

The local design editor is in:

```text
Tools/clock-design-creator-app/app/
```

See its `README.md` for run, build, validation, and browser compatibility
instructions. It exports the required folder directly as a ZIP file.

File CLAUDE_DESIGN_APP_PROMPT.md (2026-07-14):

# Prompt For Claude Design: Pi Clock Design Creator App

Use this prompt with Claude Design or another app-building assistant.

```text
Create a polished web app called "Pi Clock Design Creator" for artists and non-technical users to create exportable design packages for a Raspberry Pi art clock.

The app must create designs for this exact target format:

<design-slug>/
  loop.mp4
  pendulum.png
  theme.json

The clock display has:
- a 480 x 800 portrait canvas;
- a top circular dial cutout centered at x=240, y=250, radius=200;
- a lower circular pendulum cutout centered at x=240, y=640, radius=150;
- real-time clock hands are rendered by the Raspberry Pi app, not baked into the dial animation unless the user intentionally chooses that.

Core product goal:
Let a user create a dial animation and pendulum face, preview it in the real 480x800 clock layout, configure the theme JSON, validate the package, and export a zip file that can be copied to the Pi.

Required app features:

1. Project setup
- User enters design name.
- App generates a filesystem-safe slug such as "sunny-kitchen".
- User can choose a template: blank, paper-cut mandala, vintage film, geometric, color waves, photo/video import.

2. Dial animation editor
- Dial artwork is exactly 480 x 480.
- User can import an image or short video.
- User can crop/scale to a square.
- User can create simple procedural animations such as rotating layers, breathing scale, drifting shapes, waves, film grain, or color cycling.
- User can preview a seamless loop.
- Export must produce loop.mp4 at 480x480, preferably H.264, 15 fps, 4-10 seconds, no audio.

3. Pendulum editor
- Pendulum artwork target is 300 x 400 transparent PNG.
- The pivot must be at the top center of the image.
- Show a pivot guide line and lower circular cutout guide.
- User can design a bob/rod using shapes, colors, imported images, or SVG-like controls.
- Export must produce pendulum.png with transparency.

4. Clock theme editor
- Let the user configure:
  - hour hand color, width, length, shape;
  - minute hand color, width, length, shape;
  - second hand visible/hidden, color, width, length;
  - accent color;
  - background color;
  - dial markings: none, ticks, numerals, both;
  - pendulum period_s;
  - pendulum amplitude_deg;
  - pendulum pivot;
  - bottom backdrop: loop, solid, none;
  - bottom color when solid;
  - ambiance day_night, twinkle, glow.
- Generate theme.json exactly in this schema:

{
  "name": "Sunny Kitchen",
  "accent": "#ffb70f",
  "background": "#050505",
  "hands": {
    "hour": {
      "color": "#063d3a",
      "width": 11,
      "length": 0.42,
      "glow": false,
      "shape": "rounded"
    },
    "minute": {
      "color": "#063d3a",
      "width": 9,
      "length": 0.66,
      "glow": false,
      "shape": "rounded"
    },
    "second": {
      "color": "#ffb70f",
      "width": 2,
      "length": 0.85,
      "glow": false,
      "visible": false
    }
  },
  "dial": {
    "markings": "none",
    "color": "#ffffff",
    "count": 12
  },
  "pendulum": {
    "period_s": 1.6,
    "amplitude_deg": 9,
    "pivot": [0.5, 0.035],
    "rod_length": 0.74
  },
  "bottom": {
    "backdrop": "solid",
    "color": "#000000"
  },
  "ambiance": {
    "day_night": false,
    "twinkle": false,
    "glow": false
  }
}

5. Live preview
- Show the full 480x800 clock layout.
- Top circle displays the dial animation.
- Draw the real-time hour/minute/optional second hands over the animation.
- Lower circle displays the selected bottom backdrop and the pendulum image swinging.
- Provide play/pause and time scrub controls.
- Preview should match the Raspberry Pi app geometry.

6. Validation
- Before export, validate:
  - design slug is filesystem safe;
  - loop animation exists and is 480x480;
  - pendulum image exists and has transparency;
  - theme.json is valid;
  - video length is 4-10 seconds preferred;
  - fps is 15 preferred;
  - no missing required files.
- Show clear errors and warnings.

7. Export
- Export a zip named <design-slug>.zip.
- The zip must contain one top-level folder named <design-slug>.
- The folder must contain:
  - loop.mp4
  - pendulum.png
  - theme.json
  - preview.png optional
  - README.txt optional
- Include copy instructions after export:
  - SD card path: piclock-designs/<design-slug>/
  - SCP path: scp -r <design-slug> terry@192.168.1.217:/home/terry/piclock-designs/

UI design requirements:
- Make the first screen the actual editor, not a marketing page.
- Use a professional creative-tool layout with a left tool panel, center preview canvas, and right inspector.
- Use compact controls, icons, color swatches, sliders, toggles, and tabs.
- Include templates and sensible defaults so a user can export a working design quickly.
- Keep all text inside controls readable on laptop-sized screens.

Implementation preference:
- Build as a browser app using React or a similar framework.
- Use HTML canvas or WebGL for preview.
- Use ffmpeg.wasm or a backend export service if needed to create MP4 files.
- If MP4 export is too heavy in the browser, export image frames plus a clear server-side conversion command, but the final product should aim to export loop.mp4 directly.

Do not create a landing page. Build the editor experience directly.
```

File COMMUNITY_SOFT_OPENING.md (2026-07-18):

# Community Soft Opening

The first public release uses the existing EC2 instance and designer hostname:

<https://designer.18-191-209-51.sslip.io>

The root URL is the public project landing page. The designer is at `/designer`,
the community gallery is at `/community`, the artist guide is at `/artists`, the
DIY Raspberry Pi guide is at `/build`, and administration is at `/admin`.

It is intentionally a low-cost validation release. The browser designer remains
usable without an account. The Community page adds public browsing and downloads,
while registration is required for design submission, likes, and comments.

## Included in this release

- Artist registration and sign-in with server-side sessions.
- Editable artist name and required dial watermark metadata.
- Validated ZIP and preview upload from the designer.
- Pre-publication review: new submissions remain private until an administrator
  approves them.
- Immediate administrator email for each new submission, with its preview and a
  secure link to the review queue.
- Searchable gallery with newest, most liked, and most downloaded sorting.
- Design detail, comments, likes, and direct package downloads.
- Community reporting for copyright, inappropriate content, spam, broken packages,
  and other issues.
- Private administration for report resolution, design hide/restore, artist
  suspend/restore, and moderation audit history.
- Bundled repository designs seeded into the gallery without changing `designs/`.
- Upload size limits, ZIP path validation, request rate limits, CSRF protection,
  secure cookies, and same-origin checks.
- Daily local SQLite backups retained for 14 days.

## Current limits

- Accounts do not yet have email verification or password recovery.
- SQLite, packages, previews, and backups live on one EC2 instance.
- Local backups do not protect against instance or volume loss.
- No CDN, object storage, autoscaling, or multi-instance API is configured.

These limits are acceptable for a controlled soft opening, but not for an unmonitored
large public launch. Keep the existing AWS budget alerts enabled and monitor storage,
traffic, service logs, and the pending-review queue. Existing designs that were
already published before this workflow was introduced remain published.

## Operator checks

```bash
curl https://designer.18-191-209-51.sslip.io/api/health
ssh -i Amazon_certificate/Terryt.pem ubuntu@18.191.209.51 \
  'sudo systemctl status piclock-community caddy --no-pager'
ssh -i Amazon_certificate/Terryt.pem ubuntu@18.191.209.51 \
  'sudo journalctl -u piclock-community -n 100 --no-pager'
ssh -i Amazon_certificate/Terryt.pem ubuntu@18.191.209.51 \
  'sudo systemctl status piclock-admin-submissions.timer --no-pager'
ssh -i Amazon_certificate/Terryt.pem ubuntu@18.191.209.51 \
  'sudo du -sh /var/lib/pi-clock-community'
```

Backups are stored in `/var/lib/pi-clock-community/backups/`. Copy them to another
machine or S3 before inviting a wider audience.

## Promotion criteria

Move uploads and previews to S3, add off-host database backups, email verification,
password recovery, and error monitoring before a broad launch. PostgreSQL becomes
appropriate when traffic or concurrent writes outgrow the single-instance SQLite
service. If review volume grows, add trusted-artist approval rules or a multi-admin
queue instead of bypassing pre-publication review globally.

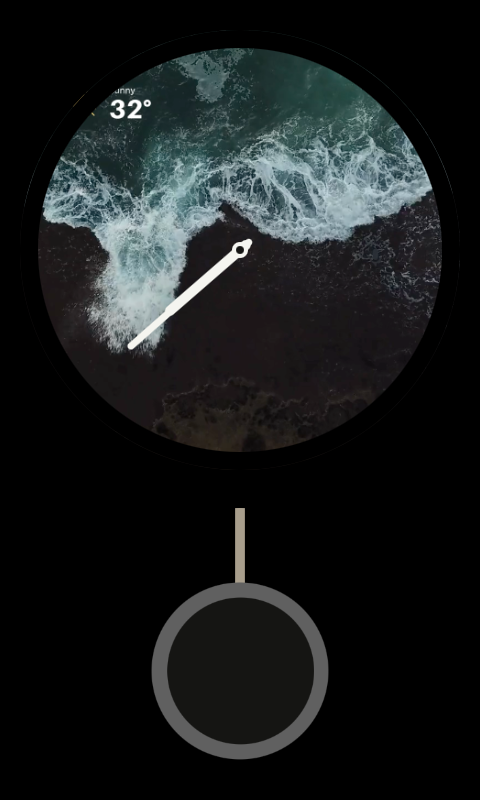
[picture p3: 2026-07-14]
designs/vintage-film/preview.png

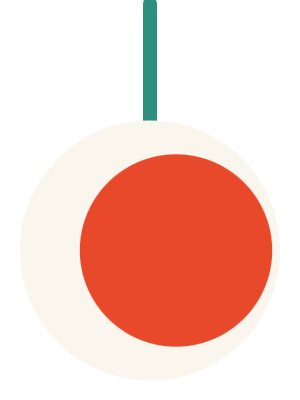
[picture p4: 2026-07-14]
designs/paper-cut/pendulum.png

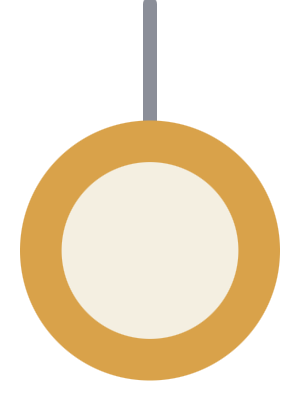
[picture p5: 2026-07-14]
designs/Night/pendulum.png

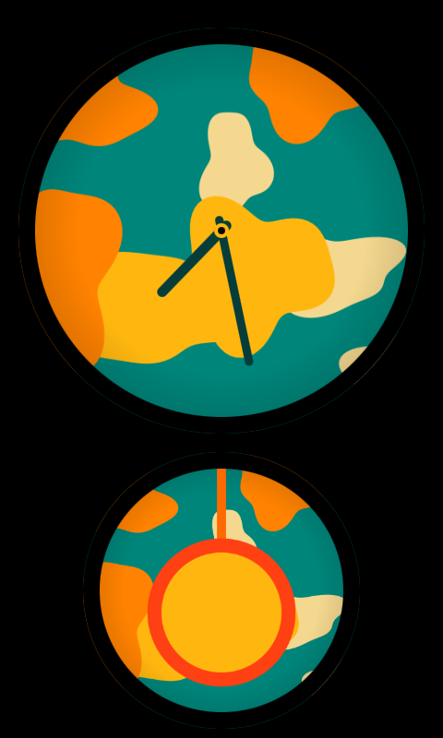
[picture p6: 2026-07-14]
designs/kitchen-pop/preview.png

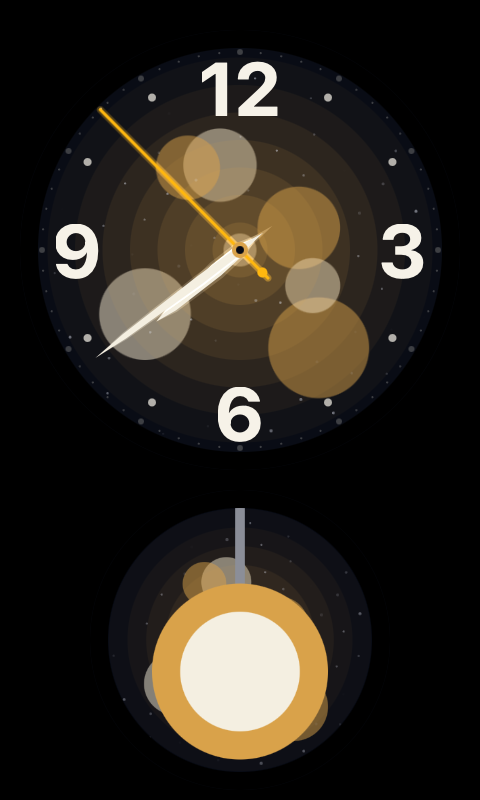
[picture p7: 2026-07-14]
designs/Night/preview.png

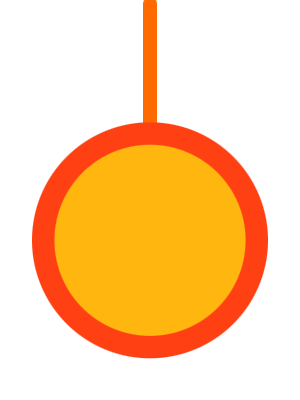
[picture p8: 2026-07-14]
designs/kitchen-pop/pendulum.png

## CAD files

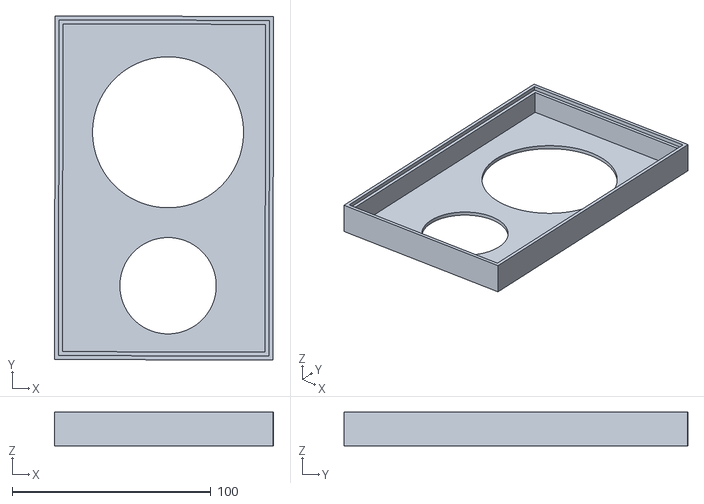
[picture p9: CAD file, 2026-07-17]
3d_enclosure/clock_face.stl
110.3 x 173.2 x 17.0

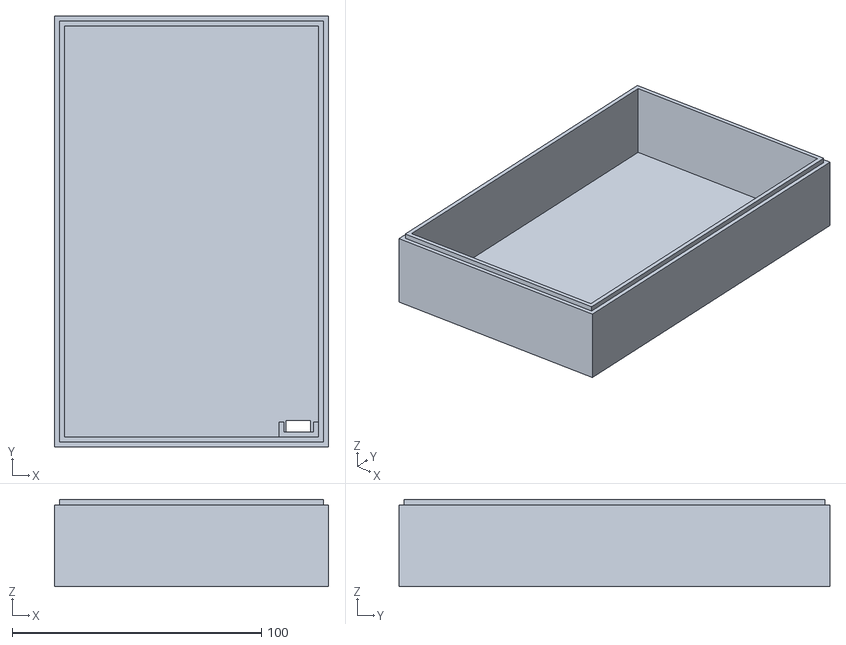
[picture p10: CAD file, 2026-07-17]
3d_enclosure/clock_back.stl
110.0 x 173.0 x 35.0

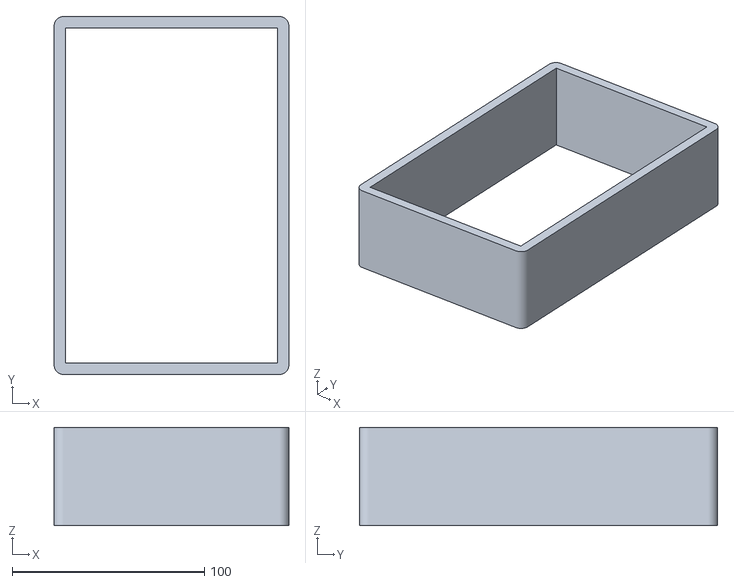
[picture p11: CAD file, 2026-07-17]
3d_enclosure/clock_frame.stl
122.0 x 186.0 x 51.0

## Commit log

2026-07-17 Add printable clock enclosure models
    [clock_back.stl, clock_face.stl, clock_frame.stl]
2026-07-18 Add public community landing and DIY guides
